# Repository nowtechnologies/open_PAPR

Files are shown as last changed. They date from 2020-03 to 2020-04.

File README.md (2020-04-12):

# Open Design PAPR 

Powered Air Purifying Respirator

### About (HUN)

Az OpenPAPR egy akkumulátoros üzemu, hordozható, motoros légtisztító légzokészülék, amely elsosorban egészségügyi dolgozók védelmére szolgál fertozésveszélyes környezetben. A Covid-19 világjárvánnyá válásával megnehezült a védoeszközök, illetve alkatrészeik beszerzése. Ezt szeretnénk áthidalni ezzel a tervvel, és referencia megvalósítással, amelyhez a piacon még elérheto komponenseket választottunk. Ezek a kínálat változásával szabadon cserélhetoek hasonló komponensekre. A készülék szabadon utánépítheto az aktuálisan elérheto alkatrészekbol.
A vegyvédelmi, egészségügyi vagy búvár maszk légmentesen zár, ezáltal véd a közvetlen cseppfertozéstol. A szurok a be és a kilégzett levegot is szurik. Az elektromos légpumpa segíti a lélegzést, és enyhe túlnyomást biztosít a maszkban, ami segíti elkerülni a potenciálisan vírusokat tartalmazó levego beszívását.

### Tesztek
Tesztek folytak Gyorben, Mosonmagyaróváron és a SOTE intenzívterápiás klinikáján.
Dr. Fodor Gábor, PAMOK, Gyor, KAITO véleménye:
Eloször is szeretném megköszönni a NowTech cég felajánlását illetve támogatását a Covid 19járvány   okozta   leküzdésében.  Az   általuk   felkínált   lehetoséget     már   több   európai   országbanigyekeztek   bevetni   a   megnövekedett   betegszám/betegforgalom   illetve   az   FFP2   illetve   FFP3maszkok hiánya miatt.Újdonságként kiemelendo, hogy a folyamatos magas áramlás segítségével egy PAPR ( pozitiívnyomású maszk )maszkot hoztak létre. HME filterek cseréjével, melyek a kórházakban nagyobbmennyiségben is elérhetoek, fokozható a biztonság az orvosok/ápolók munakvégzése során. Nemkell félni ha rosszul helyezzük fel az FFP2/3 maszkot, a folyamatos pozitiv nyomás miatt elvileg avisszalégzés/vírussal fertozött levego belégzése esélytelen.
A képeken is látható PAPR prototípus felhasználásra került otthoni használatban, egész nap igyekezetem viselni. A próba során hordozható szaturációcsipeszt helyeztem   magamra,   nehézlégzést,   légszomjat   nem   éreztem,   esetleges   fáradtságérzékelésekor az áramláson emeltem ( 6 emelet lépcsozést követoen 70l/min-re ) , így 3 óránkeresztül hordtam. Nálam 35-50 l/min áramlás mellett volt elfogadható a használata, feltételezem egyénenként változik. Jelenlegi járványügyi helyzetben feltétlenül javasolnám szélesebb köru tesztelését, hiszen a járványkatasztrófa   elotti   állapotában   vagyunk,   lenne   lehetoség   a   korai   felkészülésre,   módosításra, egyeztetésekre   szélesebb   körben.   (   klinikák/megyei   járvány   centrumok   )   Kiemelendo, hogy elkészítés  során döntoen olyan anyagok felhasználása, mely a kórházakban elérheto nagyobbmennyiségben, validáltak, biztonságosak. Amennyiben   a   járvány   kiszélesedik   és   sok   lélegeztetett   beteget   kellene   gondozni,   a   maszklevételének számának csökkentése illetve a PAPR újrasterilizálása fokozhatná az ellátó személyzetbiztonságát. Az intenzvíen dolgozók védelme meg több szempontból is kezelések sikerességétnöveli, a betegek hosszú távú túlélésnek a kulcsa.

### Block diagram

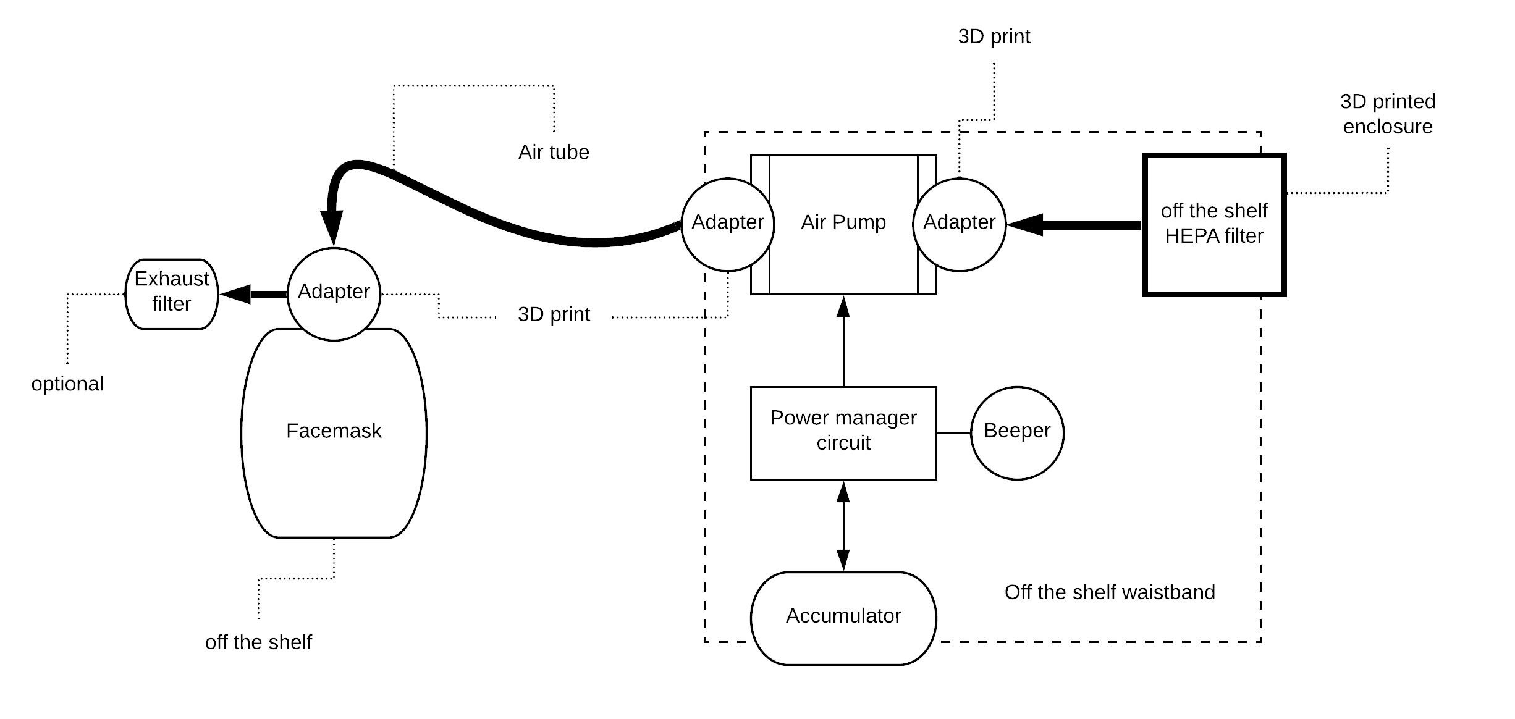
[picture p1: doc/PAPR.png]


### Photos

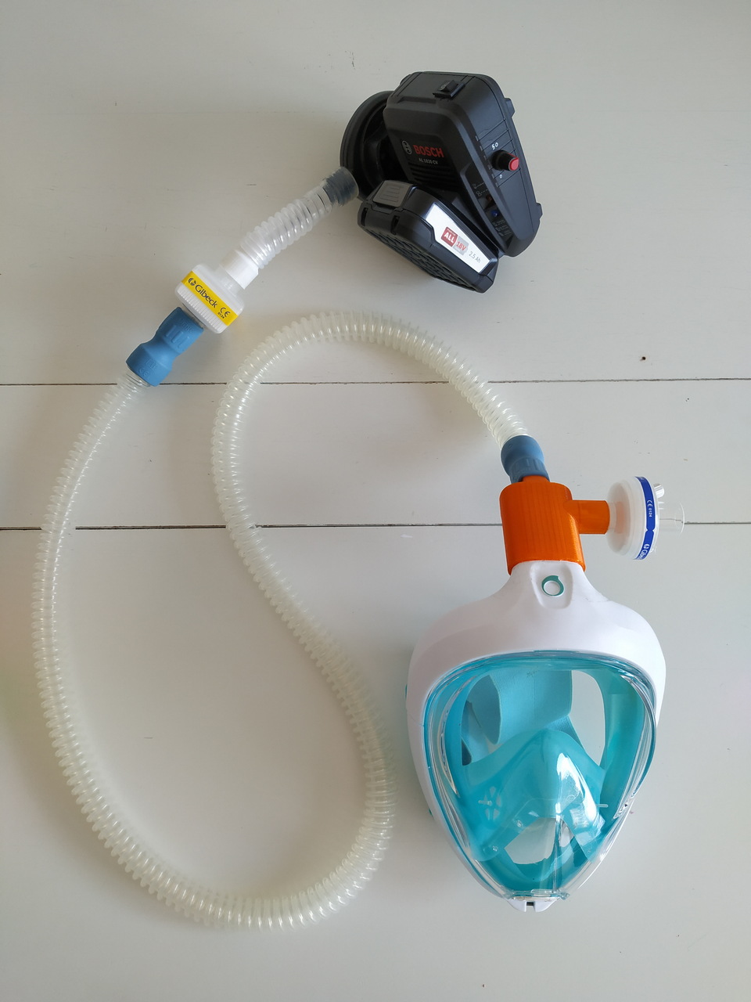
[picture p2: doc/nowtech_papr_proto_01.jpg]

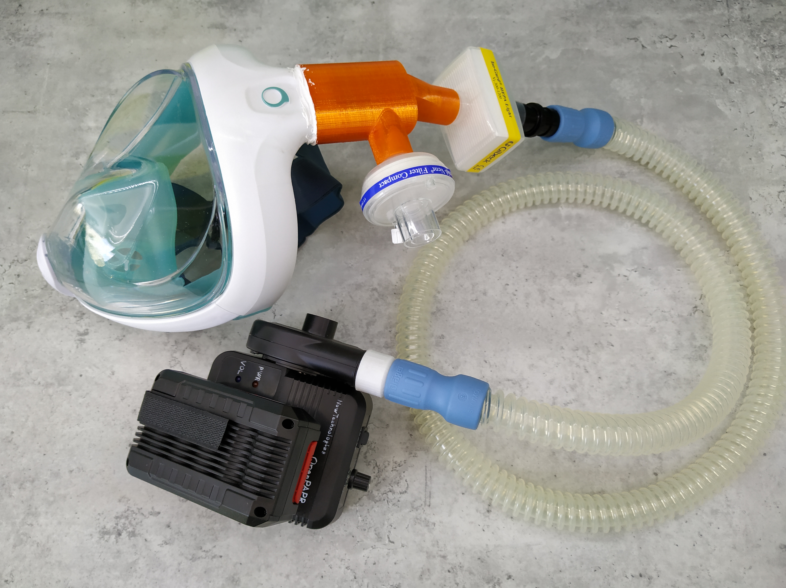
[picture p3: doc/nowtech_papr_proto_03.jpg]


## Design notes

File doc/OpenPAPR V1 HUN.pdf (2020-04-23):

# OpenPAPR V1

## Használati útmutató és műszaki leírás

# 1 Leírás

Az OpenPAPR egy akkumulátoros üzemű, hordozható, motoros légtisztító légzőkészülék, amely elsősorban egészségügyi dolgozók védelmére szolgál fertőzésveszélyes környezetben. A Covid-19 világjárvánnyá válásával megnehezült a védőeszközök, illetve alkatrészeik beszerzése. Ezt szeretnénk áthidalni ezzel a tervvel, és referencia megvalósítással, amelyhez a piacon még elérhető komponenseket választottunk. Ezek a kínálat változásával szabadon cserélhetőek hasonló komponensekre. A készülék szabadon utánépíthető az aktuálisan elérhető alkatrészekből.
A tervek elérhetőek a projekt Guthub oldalán: https://github.com/nowtechnologies/open_PAPR A vegyvédelmi, egészségügyi vagy búvár maszk légmentesen zár, ezáltal véd a közvetlen cseppfertőzéstől. A szűrők a be és a kilégzett levegőt is szűrik. Az elektromos légpumpa segíti a lélegzést, és enyhe túlnyomást biztosít a maszkban, ami segíti elkerülni a potenciálisan vírusokat tartalmazó levegő beszívását.
NowTechnologies | OpenPAPR | 1/14

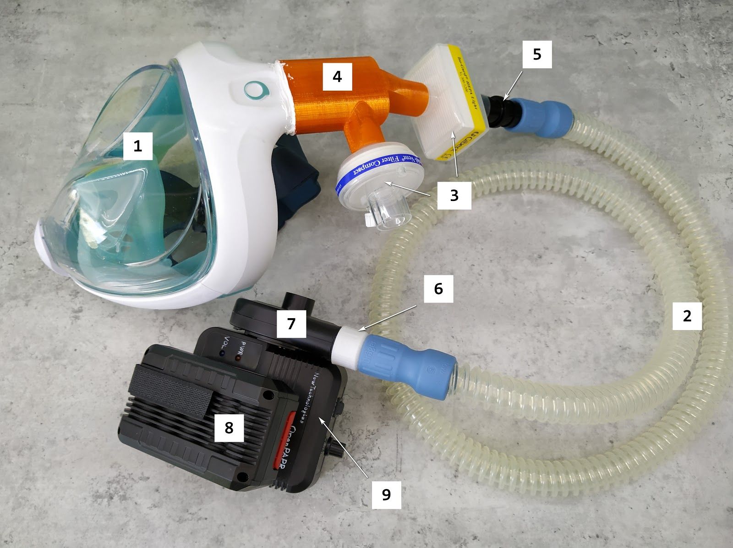
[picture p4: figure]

1. Kép. Az összeállított készülék

# 2 Használat

Helyezzük az akkumulátort az akkumulátor gyorcsatlakozóra, és rögzítsük véletlen lecsúszás ellen a tépőzárral. Csatlakoztassuk a maszk adapterre a szűrőket, a bemeneti szűrőre a gégecsövet, arra pedig a levegő fújót az 1. Képen látható módon.
A készülékház hátoldalán lévő fülbe fűzzük be a tartó övet. Vegyük fel a maszkot, húzzuk szorosra a pántjait. Kapcsoljuk be a készüléket a főkapcsolóval. Normál akkumulátor töltöttségnél folyamatosan világít a narancssárga LED, lemerült akkumulátor esetén villog, tönkrement akkumulátornál nem világít. A tartalék energia használatra a készülék 10 másodpercenkénti pittyenéssel figyelmeztet. Lemerüléskor sípol egy hosszút, lekapcsolja a légfújó motort, és folyamatos pittyegésbe kezd.
A légszállítás állító potméterrel állítsunk enyhe, még kényelmes túlnyomást a maszkban. Megnövekedett levegő szükséglet (fizikai aktivitás, az akkumulátor merülése, a szűrő eltömődése) esetén állítsunk utána menet közben is.

## 2.1 Kezelőszervek

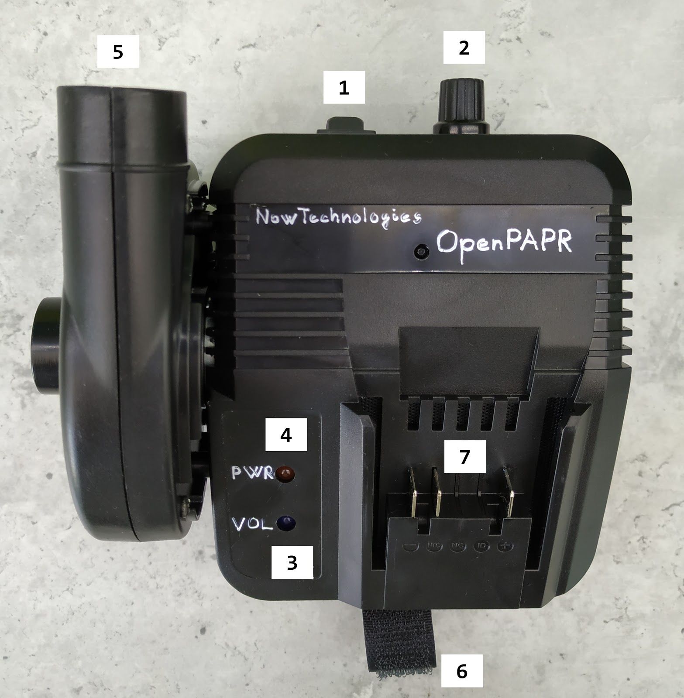
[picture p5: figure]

2. Kép. Kezelőszervek

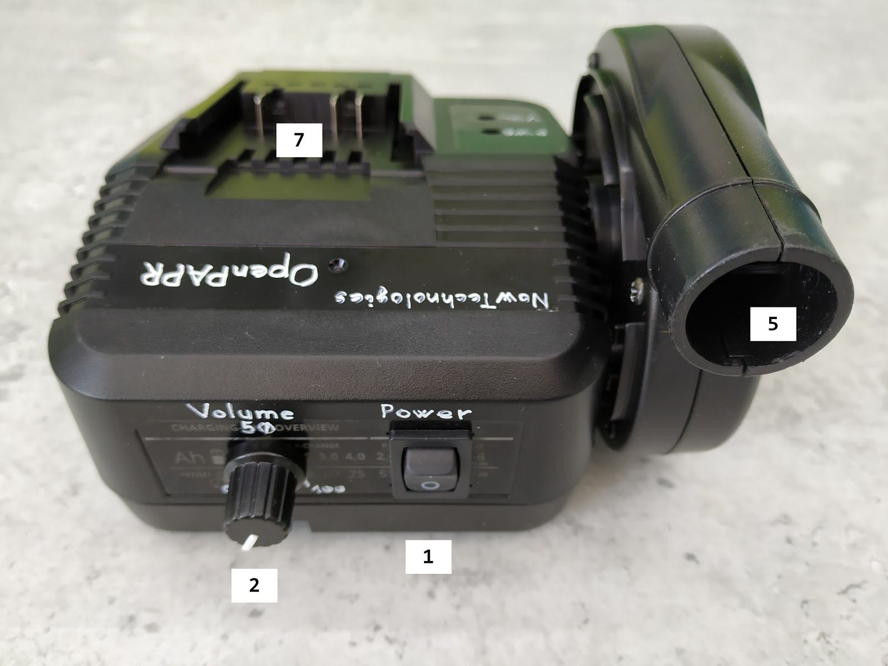
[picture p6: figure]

3. Kép. Kezelőszervek

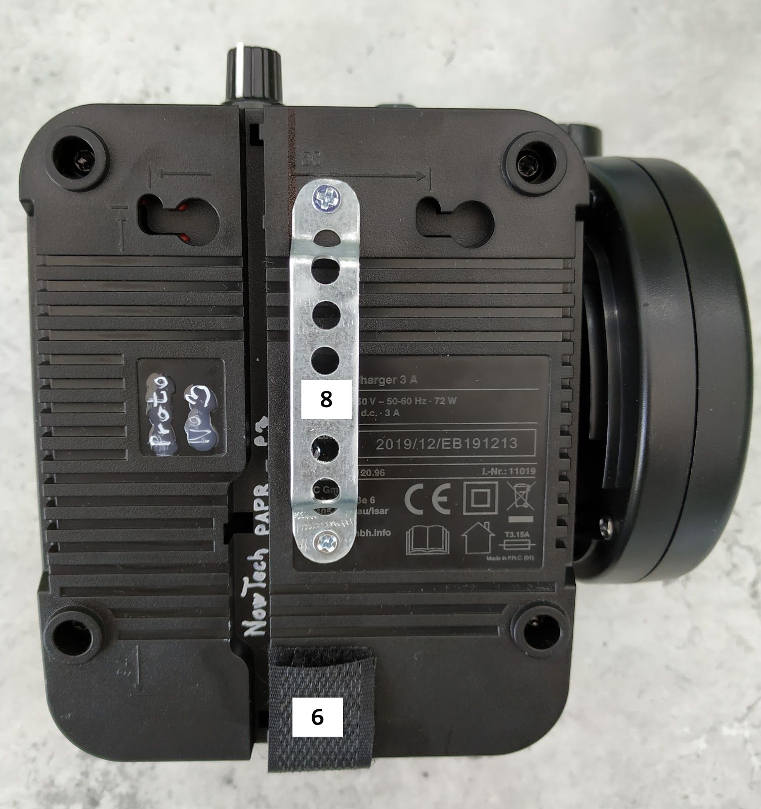
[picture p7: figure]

4. Kép. Kezelőszervek
1. Főkapcsoló.
2. Légszállítás mennyiségét állító potméter.
3. Légszállítás visszajelző LED, kék színű. Kikapcsolt légfújásnál sötét. A légszállítás növelésével arányosan, egyre rövidebb időközzel villog.
4. Bekapcsolt állapotot folyamatos fénnyel, lemerült akkumulátort villogó fénnyel jelző LED, narancs színű.
5. Levegő kiömlő cső.

6. Akkumulátor rögzítő tépőzár.
7. Akkumulátor gyorscsatlakozó.
8. Öv akasztó.

# 3 Műszaki adatok

Légszállítás szűrőn keresztül: | 12 lpm és 230 lpm között állítható
Akkumulátor: | 20 Volt Li-ion (sorban 5 cella)
Áramfelvétel: | 0.1 és 1.5 Amper között
Üzemidő: | 2 és 4 óra között
Tömeg:
Zajszint: | 80 dBa
Motor PWM frekvencia: | 1 kHz
Motor PWM kitöltés: | 5% és 40% között állítható. A felső korlát a készülékházon
| belül állítható.
Masz adapeter anyaga:
https://www.herz-hungaria.hu/adatlap/Adatlap_PETG_HERZ_FILAMENT.ung.pdf

## 3.1 Részegységek

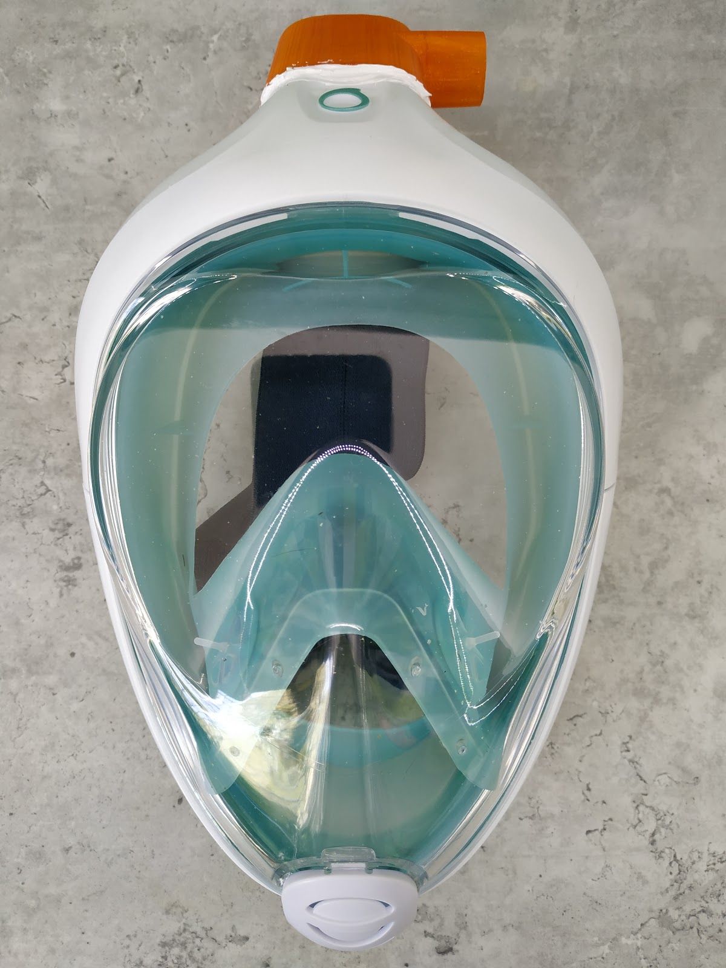
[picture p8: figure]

5. Kép. Maszk (1)

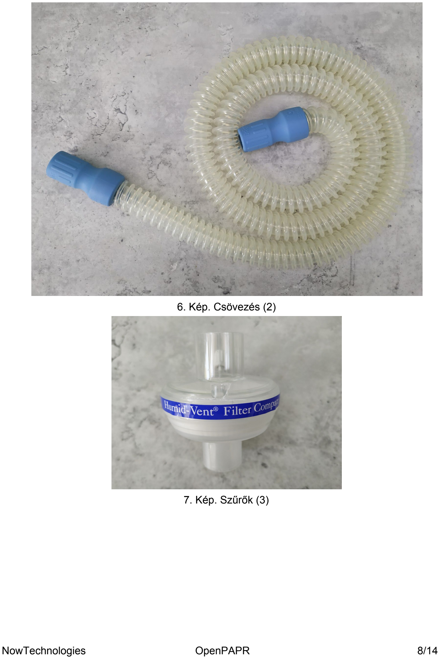
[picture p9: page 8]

6. Kép. Csövezés (2)
7. Kép. Szűrők (3)

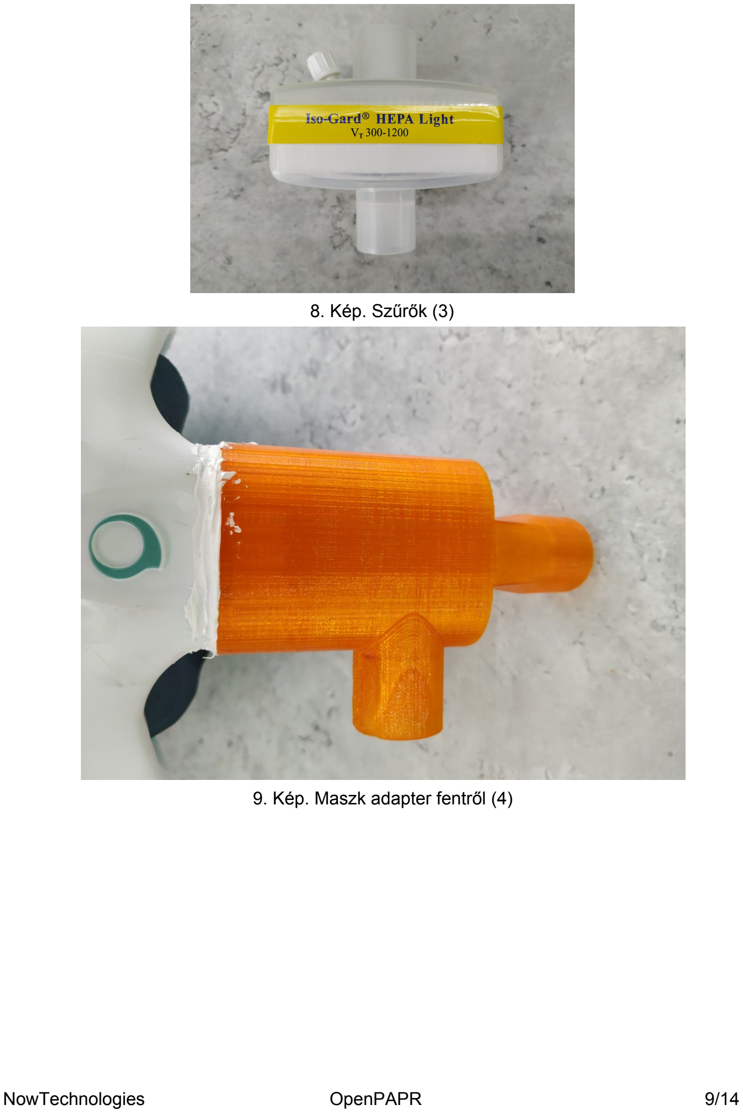
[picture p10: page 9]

8. Kép. Szűrők (3)
9. Kép. Maszk adapter fentről (4)

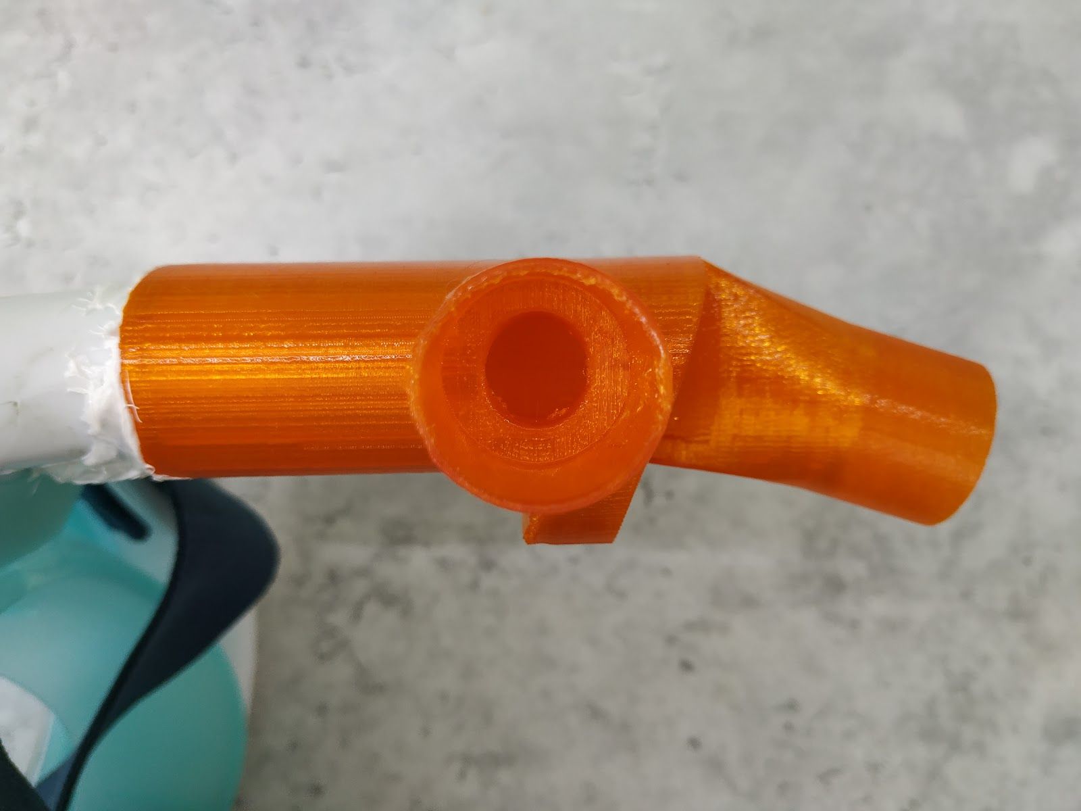
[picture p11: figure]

10. Kép. Maszk adapter oldalról (4)

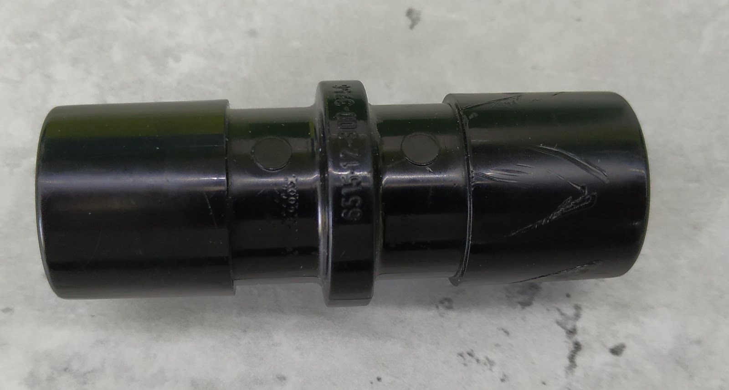
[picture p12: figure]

11. Kép. Cső adapter (5)

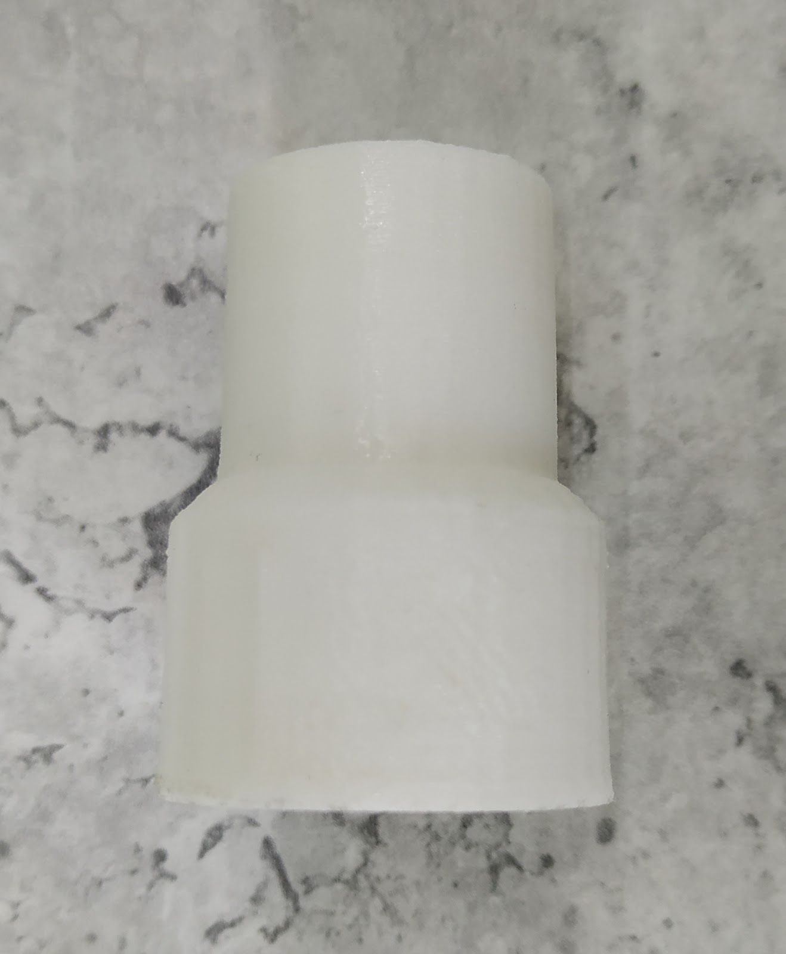
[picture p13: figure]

12. Kép. Légfújó adapter (6)

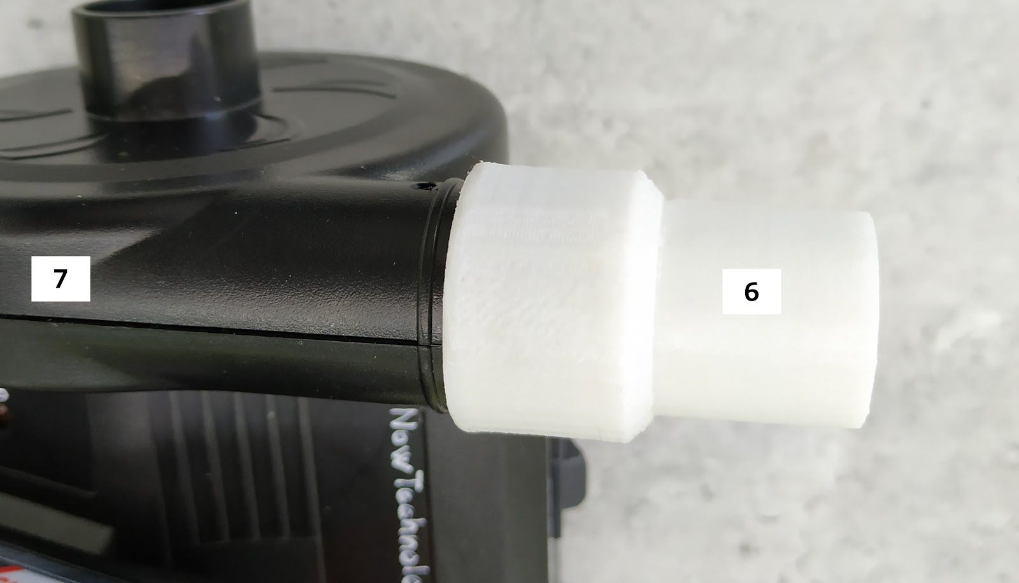
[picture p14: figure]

13. Kép. Légfújó adapter (6) a készülékre helyezve.

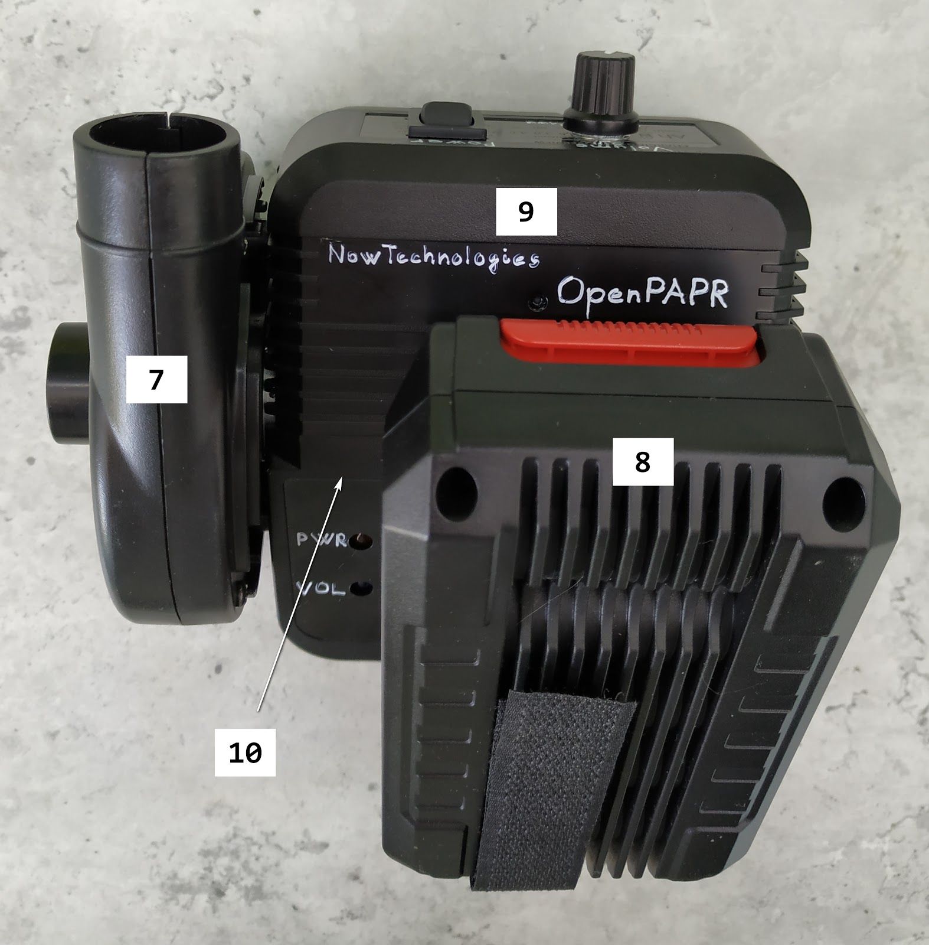
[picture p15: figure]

14. Kép. A készülékház (9), a légfújó (7), a vezérlő elektronika (10) és az akkumulátor (8) együtt.
No | | Referencia megvalósítás | Ajánlás
1 | Maszk | Decathlon Easybreath snorkel maszk. A maszk eredeti, állnál található kilégző szelepe beragasztásra került. A kilégzett levegő is felül-hátul | Bármilyen, légmentesen záródó maszk. Lehet munkavédelmi, vegyvédelmi vagy búvár célú.

| | került kivezetésre és szűrésre.
2 | Csövezés | Dräger lélegeztetőgép cső. | 22 mm belső átmérőjű cső. Lehetőleg lélegeztetőgéphez való. Hiány esetén kerti locsolótömlő is alkalmas.
3 | Szűrők | ● Iso.Grad HEPA Light VT 300-1200 ● Humid-Vent Filter Compact VT 150-1000 | Standard lélegeztetőgép szűrő. Ennek hiányában HEPA szűrő legalább H14 minősítéssel, U15 ajánlott.
4 | Maszk adapter | 3D nyomtatott (PETG), csatlakozó csonkkal a ki és a bemeneti szűrő számára. | Fontos, hogy légzáró anyagból készüljön.
5 | Cső adapter | Lélegeztetőgép tartozék cső adapter | Légtömör, 22 mm külső átmérőjű cső.
6 | Légfújó adapter | 3D nyomtatott szűkítő 24.5 mm -> 22 mm
7 | Légfújó | Tesco elektromos pumpa 12 Volt 30 Watt, csökkentett teljesítménnyel. | Bármilyen légfújó, ami alkalmas rá, hogy 2 db sorba kötött szűrön keresztül 200 liter levegőt nyomjon át percenként. A felépítendő nyomás 50 és 150 Pa között legyen.
8 | Akkumulátor | Einhell 18 Volt 2.5 Ah Li-ion szerszámgép akkumulátor. | 12 és 36 Volt közötti feszültségű, legalább 2 Ah kapacitású. Ajánlott készen kapható akkupakkok és a hozzájuk tartozó töltő alkalmazása, például a kereskedelemben nagy számban elérhető szerszámgép akkumulátorok.
9 | Készülékház | Einhell szerszámgép akkumulátor töltő készülékháza. Azért választottuk ezt, mert így adott az akkumulátor csatlakozása, ami lehetővé teszi a gyors cserét. | Keményfalú elektronikai projekt doboz, vagy villamos kötődoboz.
10 | Elektronika | ● STM32F030 mikrokontroller | ● Felhasználói felület beolvasása,

| | ● Potméteres fordulatszám beállítás ● Power LED a bekapcsolt állapot és a lemerült akkumulátor jelzésére ● Volume LED a légszállítás mennyiségének visszajelzésére ● Csipogó a merülő, illetve a lemerült akkumulátor jelzésére | nyomógombok vagy potméter. ● Motor fordulatszám változtatása. ● Akkumulátor túlmerülés védelem.
11 | Tömítés | Soudal Fix ALL Flexi UV álló ragasztó-tömítő | UV álló, jól tapadó, nedvességre és magas hőmérsékletre nem érzékeny, rugalmas tömítő-ragasztó

## 3.2 Kapcsolási rajz

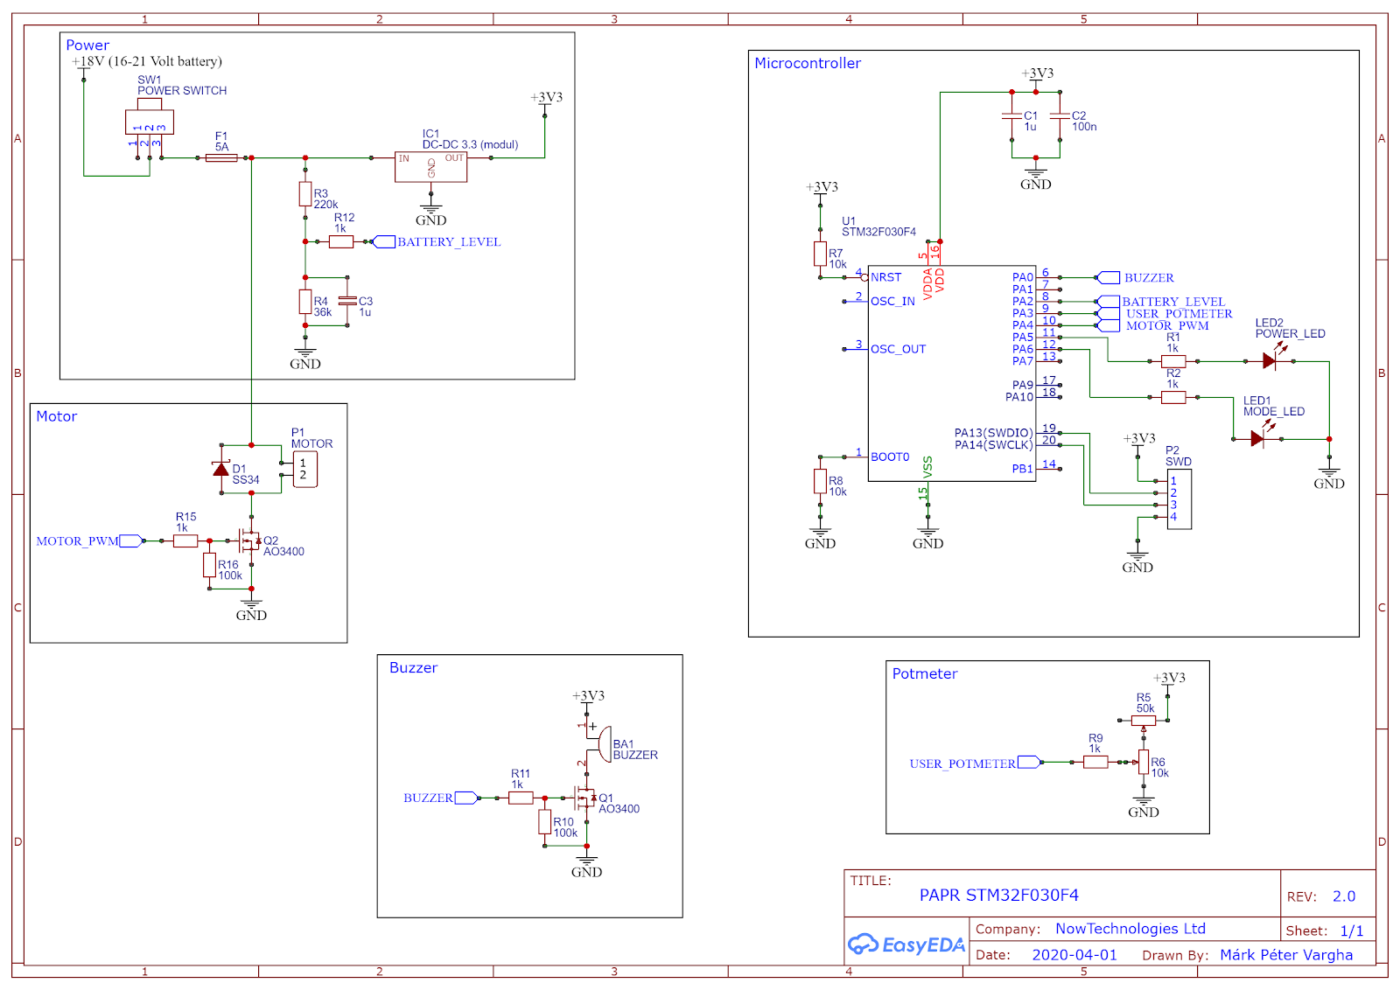
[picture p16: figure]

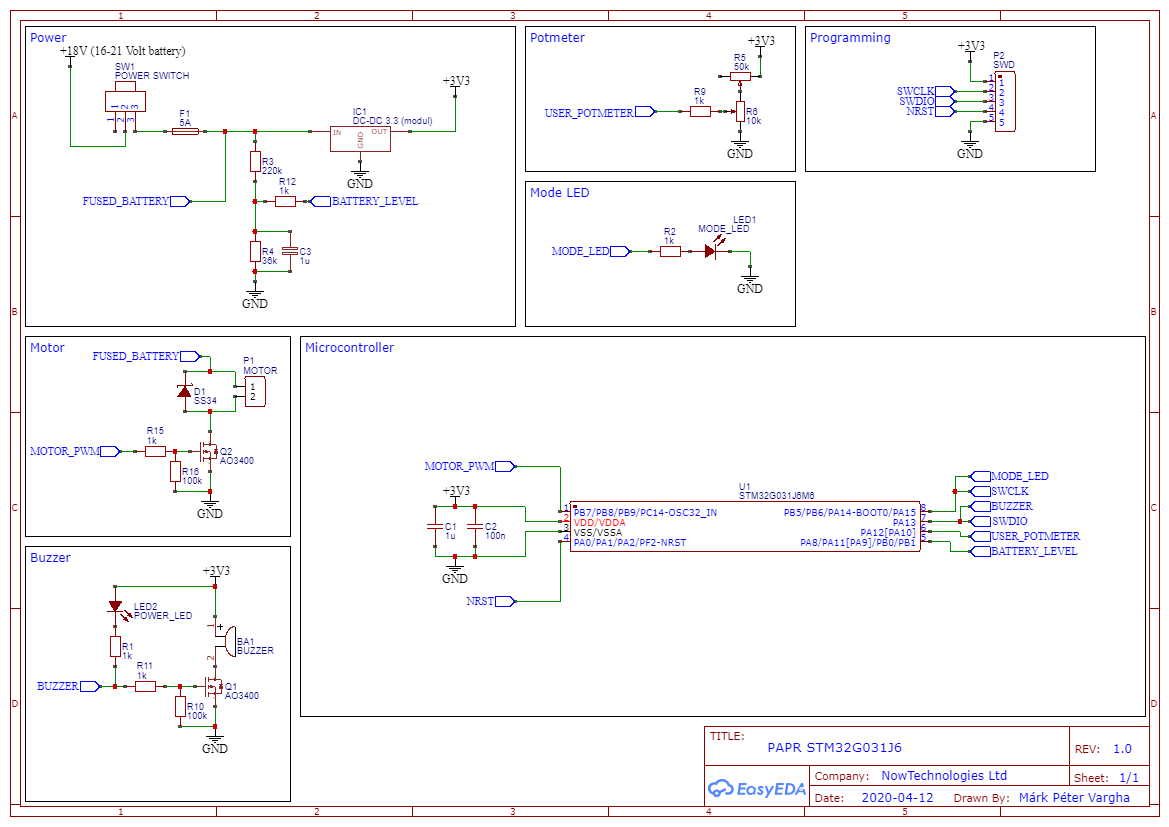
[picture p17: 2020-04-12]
doc/schematic/stm32g031j6/Schematic_PAPR_STM32G031J6_V1.png

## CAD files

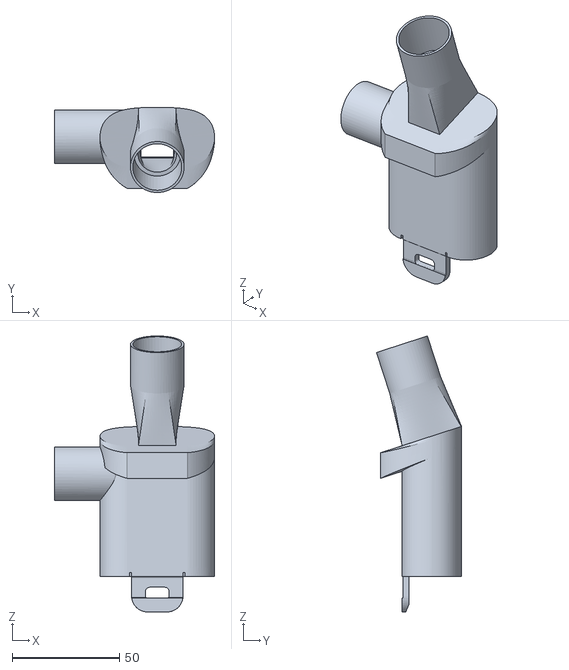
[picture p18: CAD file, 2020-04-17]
mechanical/mask_adapter_v2.stl
74.8 x 39.7 x 128.6

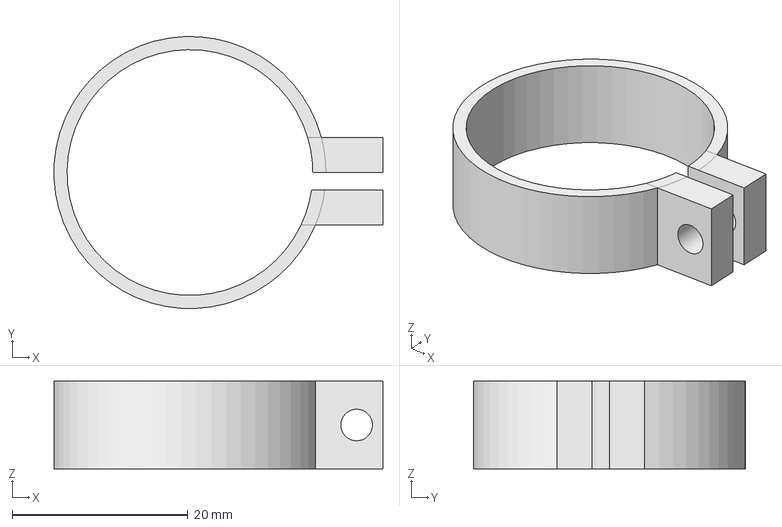
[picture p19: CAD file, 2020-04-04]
mechanical/pipe_clamp_01A.FCStd
37.5 x 31.0 x 10.0 mm

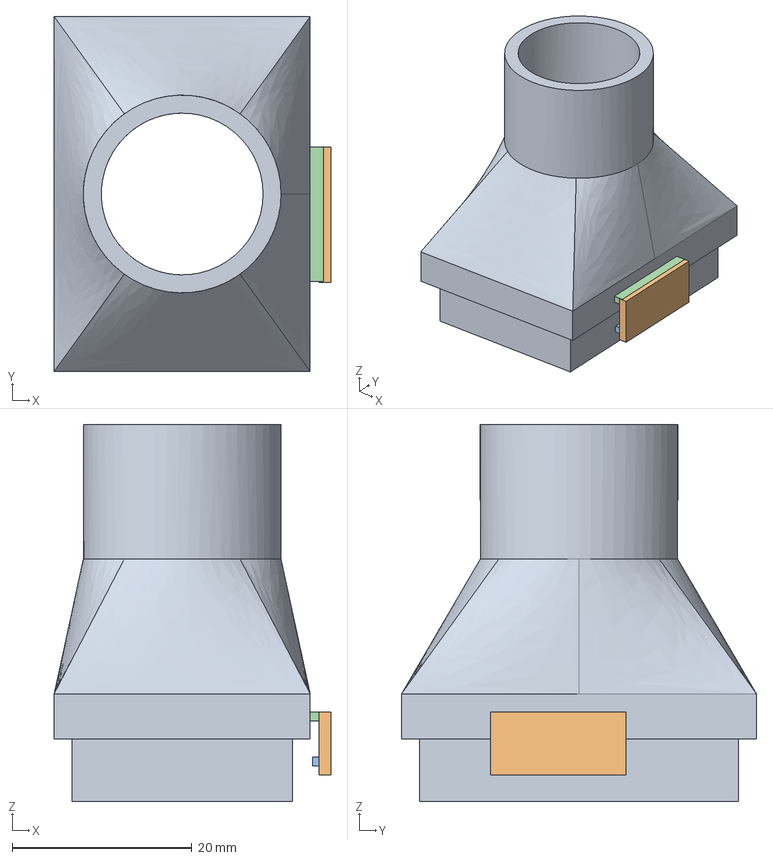
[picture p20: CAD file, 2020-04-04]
mechanical/BOSH_Illeszto_01B.FCStd
30.8 x 39.5 x 42.0 mm
Alap_test
Kocka
Kocka001

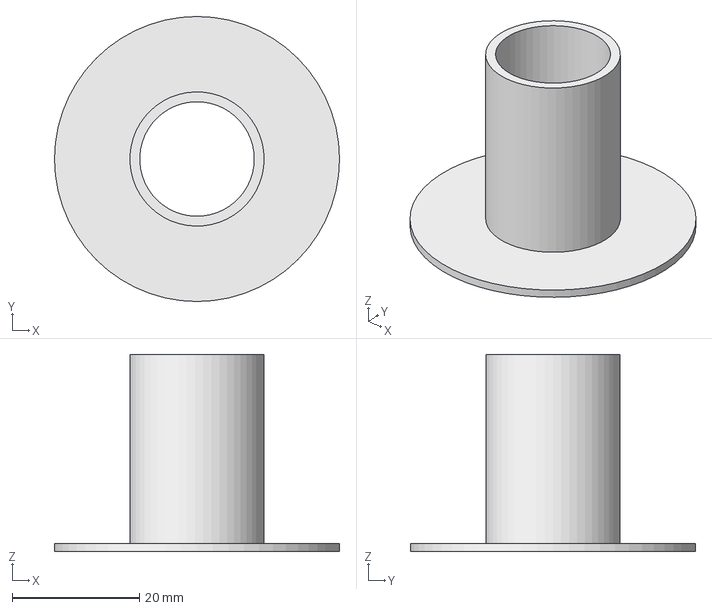
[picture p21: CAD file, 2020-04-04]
mechanical/HEPA_adapter_01A.FCStd
44.8 x 44.8 x 31.0 mm

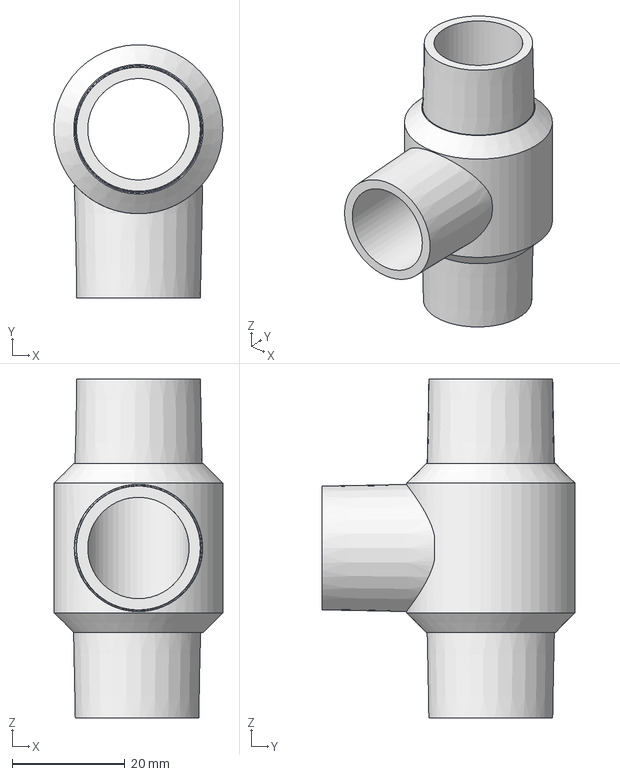
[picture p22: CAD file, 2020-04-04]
mechanical/T_pipe_01B.FCStd
30.0 x 45.0 x 60.2 mm

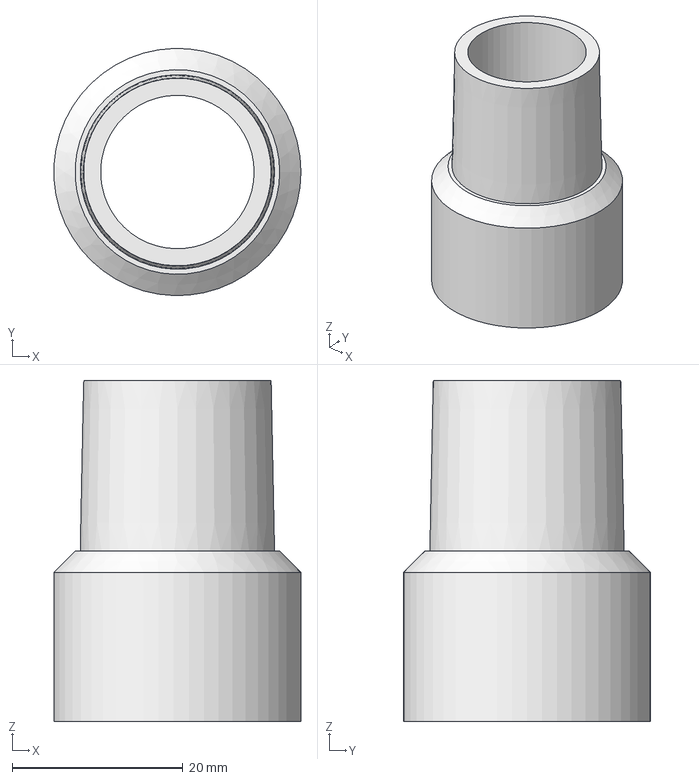
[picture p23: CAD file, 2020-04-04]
mechanical/pipe_adapter_01A.FCStd
29.0 x 29.0 x 40.0 mm

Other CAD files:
mechanical/BOSH_Illeszto_01B.stl
mechanical/HEPA_adapter_01A.stl
mechanical/T_pipe_01B.stl
mechanical/pipe_adapter_01A.stl
mechanical/pipe_clamp_01A.stl

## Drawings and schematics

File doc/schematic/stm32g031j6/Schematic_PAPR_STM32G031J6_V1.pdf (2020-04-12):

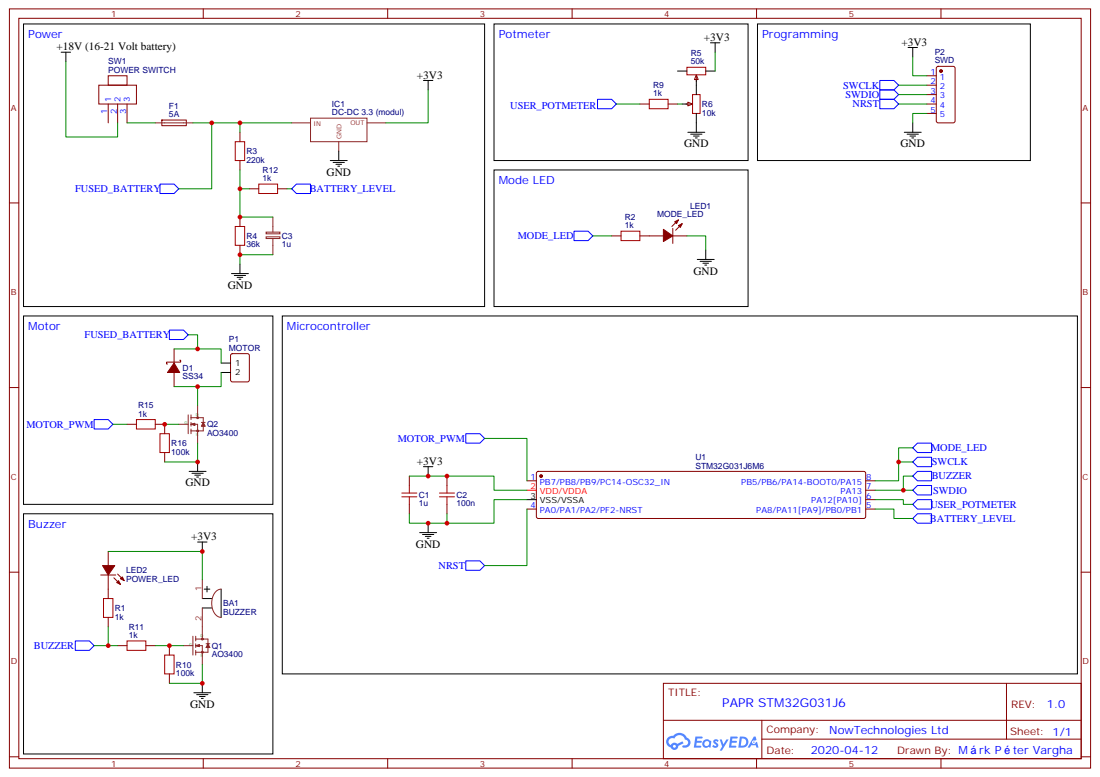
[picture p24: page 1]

Drawn By: M rk P ter Vargha

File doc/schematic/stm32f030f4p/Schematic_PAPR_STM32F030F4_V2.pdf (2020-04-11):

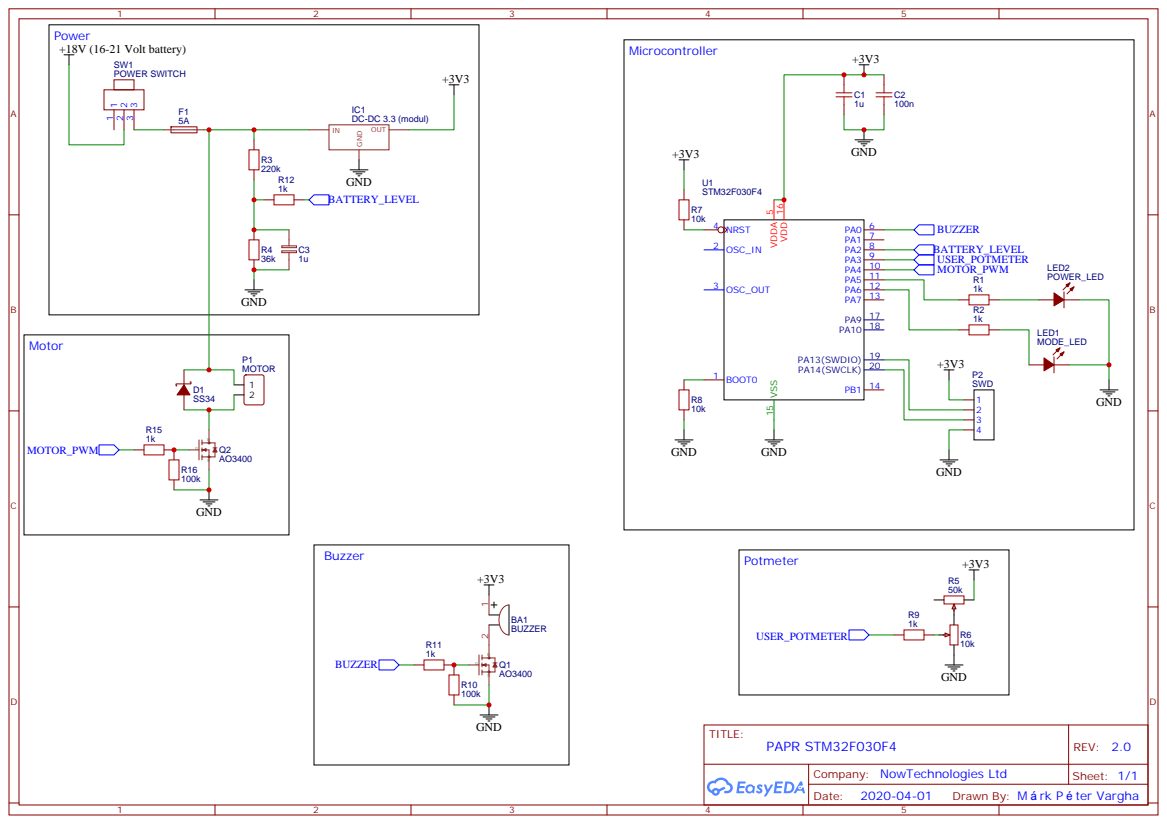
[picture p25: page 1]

Drawn By: M rk P ter Vargha

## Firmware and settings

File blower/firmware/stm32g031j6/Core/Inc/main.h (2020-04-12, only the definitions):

#define PWM_MOTOR_IN_Pin GPIO_PIN_9
#define PWM_MOTOR_IN_GPIO_Port GPIOB
#define ADC_BATTERY_Pin GPIO_PIN_0
#define ADC_BATTERY_GPIO_Port GPIOB
#define ADC_POT_Pin GPIO_PIN_12
#define ADC_POT_GPIO_Port GPIOA
#define BUZZER_Pin GPIO_PIN_13
#define BUZZER_GPIO_Port GPIOA
#define MODE_LED_Pin GPIO_PIN_14
#define MODE_LED_GPIO_Port GPIOA

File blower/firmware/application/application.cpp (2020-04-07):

#include "common.h"
#include "application.h"

namespace {
  constexpr uint32_t cLoopDelayMs =                      5u;
  constexpr uint32_t cAdcPollIntervalMs =               10u;
  constexpr uint32_t cBatteryOverLimitSampleCount =   2000u; // 1000 = ~12 sec
  constexpr uint32_t cModeLedOnTimeMs =                 25u;  // Blink ON time
  constexpr uint32_t cBuzzerOnTimeMs =                 100u; // Beep ON time
  constexpr uint32_t cBuzzerOnTimeWhenBatteryDeadMs = 1000u; // Long beep when battery level goes below minimum
  constexpr uint32_t cBuzzerWarningIntervalMs =      10000u; // Battery warning beep interval
  constexpr uint32_t cBuzzerLowIntervalMs =            200u; // Battery warning beep interval
  constexpr uint32_t cPwmLowLimit =                   papr::cPwmMax / 20u; // Minimum PWM
  constexpr uint32_t cAdcPotmeterLowLimit =           papr::cAdcMax / 20u;
  constexpr uint32_t cBatteryMinOffRawValue =         2794u; // 16.00 V, cut off limit
  constexpr uint32_t cBatteryWarningRawValue =        2968u; // 17.00 V, warning limit
  constexpr uint32_t cBatteryChargedRawValue =        3666u; // 21.00 V
  
  void startupBeep() {
    constexpr auto beeps = 2u;
    constexpr auto delayMs = 100u;
    constexpr auto beepMs = 40u;
    for (auto i = 0u; i < beeps; i++) {
      papr::turnOnBuzzer();
      papr::delayMs(beepMs);
      papr::turnOffBuzzer();
      if (i < beeps - 1) {
        papr::delayMs(delayMs);
      }
    }  
  }

}

extern "C" void applicationLoop() {
  uint32_t pwm = 0x0u;
  uint32_t adcPollTimestamp;
  uint32_t powerLedTimestamp;
  uint32_t powerLedIntervalMs = 50u;
  uint32_t modeLedTimestamp;
  uint32_t modeLedIntervalMs = 100u;
  uint32_t buzzerTimestamp;
  uint32_t buzzerInterval = cBuzzerWarningIntervalMs;
  int32_t batteryWarningSampleCount = 0;
  int32_t batteryMinOffSampleCount = 0;
  uint32_t batteryRawValue;
  uint32_t potmeterRawValue;
  papr::BatteryLevelCounter batteryLevel(cBatteryMinOffRawValue, cBatteryWarningRawValue, cBatteryOverLimitSampleCount);
  
  papr::turnOnPowerLed();
  uint32_t counter = 100u;
  while(papr::getBatteryValue() < cBatteryMinOffRawValue && --counter > 0) {
    for (auto i = 0u; i < 20; i++) {
      batteryLevel.update(papr::getBatteryValue());
    }
    papr::delayMs(10u);
  }
  
  startupBeep();
  
  while(true) {
    uint32_t now = papr::getTick();
    
    // Check ADC
    if (now - adcPollTimestamp > cAdcPollIntervalMs) {
      batteryRawValue = papr::getBatteryValue();
      potmeterRawValue = papr::getPotmeterValue();
      if (batteryLevel.update(batteryRawValue)) { // Battery state changed
        if (batteryLevel == papr::BatteryLevel::cBatteryLow) {
          papr::setMotorPwm(0u);
          papr::turnOnBuzzer();
          papr::delayMs(cBuzzerOnTimeWhenBatteryDeadMs);
          papr::turnOffBuzzer();
          buzzerInterval = 0;
        }
        else if (batteryLevel == papr::BatteryLevel::cBatteryWarning) {
          papr::turnOnPowerLed();
          papr::turnOffBuzzer();
        }
        else if (batteryLevel == papr::BatteryLevel::cBatteryOk) {
          papr::turnOnPowerLed();
          papr::turnOffBuzzer();
        }
        else {
          // Doin' Nothin'
        }
      }
      adcPollTimestamp = now;
    }
    
    // Calculate PWM from potmeter
    if (potmeterRawValue < cAdcPotmeterLowLimit) {
      pwm = 0;
    }
    else {
      pwm = papr::map(potmeterRawValue, cAdcPotmeterLowLimit, papr::cAdcMax, cPwmLowLimit, papr::cPwmMax);
    }
    
    // Set PWM to 0 when battery is low
    pwm = batteryLevel.notLow() ? pwm : 0u;
    papr::setMotorPwm(pwm);
    
    // Handle PWM related mode LED blinking
    if (pwm == 0) {
      papr::turnOffModeLed();
    }
    else {
      if (now - modeLedTimestamp > modeLedIntervalMs) {
        if (!papr::isModeLedOn()) {
          papr::turnOnModeLed();
          modeLedIntervalMs = cModeLedOnTimeMs;
        }
        else {
          papr::turnOffModeLed();
          modeLedIntervalMs = (0xFFF / 2 - pwm ) / 5;
        }
        modeLedTimestamp = now;
      }
    }
    // Handle power led blinking
    if (batteryLevel == papr::BatteryLevel::cBatteryLow && now - powerLedTimestamp > powerLedIntervalMs) {
      papr::togglePowerLed();
      powerLedTimestamp = now;
    }
    
    // Handle buzzer beeps when warning or low
    if (now - buzzerTimestamp > buzzerInterval) {
      if (batteryLevel == papr::BatteryLevel::cBatteryOk) { // Battery OK, no beep
        papr::turnOffBuzzer();
      }
      else if (batteryLevel == papr::BatteryLevel::cBatteryWarning) { // Warning beeps
        if (papr::isBuzzerOn()) {
          buzzerInterval = cBuzzerWarningIntervalMs;
          papr::turnOffBuzzer();
        }
        else {
          buzzerInterval = cBuzzerOnTimeMs;
          papr::turnOnBuzzer();
        }
      }
      else if (batteryLevel == papr::BatteryLevel::cBatteryLow) { // Battery low beeps
        if (papr::isBuzzerOn()) {
          buzzerInterval = cBuzzerLowIntervalMs;
          papr::turnOffBuzzer();
        }
        else {
          buzzerInterval = cBuzzerOnTimeMs;
          papr::turnOnBuzzer();
        }
      }
      else {
        //Doin' nothin'
      }
      buzzerTimestamp = now;
    }
    
    papr::delayMs(cLoopDelayMs);
  }
}

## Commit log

2020-03-28 Added STM32F042 IOC
2020-03-28 Added STM32F042 HAL files
2020-03-28 Added STM32F042 VisualGDB project
2020-03-28 STM32F042 blinky
2020-03-29 More devices blink
2020-03-29 F030 PWM
2020-03-29 STM32F030 6 kHz PWM
2020-03-30 Changed PWM pin
2020-03-30 Added STM32F030 binaries to git
2020-03-31 Basics on STM32F030
2020-03-31 Basic battery protection
2020-03-31 Power LED blinks on battery low
2020-04-01 Optional restart after battery low
2020-04-01 Added STM32F030F4P schematic
2020-04-02 Schematic update
2020-04-02 Pin change
2020-04-03 Updated battery monitor
2020-04-03 Battery warning and low beeps.
2020-04-03 Fixed ADC average bug
    [papr_blower_stm32f030f4p_bsp.cpp]
2020-04-04 Added 3D design files
    [BOSH_Illeszto_01B.FCStd, BOSH_Illeszto_01B.stl, CSO_adapter_01A.stl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]
2020-04-05 Timed ADC poll
2020-04-05 Added STM32G031 BSP
2020-04-05 Added G030 20 pin TSSOP variant
2020-04-06 Fixed hardware handler's reference
    [papr_blower_stm32f030f4p_bsp.cpp, papr_blower_stm32g031j6_bsp.cpp]
2020-04-07 Startup battery test
2020-04-07 Fine tuning UI and PWM
2020-04-07 Battery protection enabled
2020-04-08 Schematic update. Changed Bridge IC to MOSFET.
2020-04-10 PWM frequency changed to 1 kHz
2020-04-12 Added STM32G031 schematic
2020-04-12 Schematic moved
2020-04-13 G031 pinout and ADC DMA
2020-04-17 Added mask adapter
    [HEPA_adapter_01A.FCStd, HEPA_adapter_01A.stl, T_pipe_01B.FCStd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]
2020-04-23 Added mask adapter material.

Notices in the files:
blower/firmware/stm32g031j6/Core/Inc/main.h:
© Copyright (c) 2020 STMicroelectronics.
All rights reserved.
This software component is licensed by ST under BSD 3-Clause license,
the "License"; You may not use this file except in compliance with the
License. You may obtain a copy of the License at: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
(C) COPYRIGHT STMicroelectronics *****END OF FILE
